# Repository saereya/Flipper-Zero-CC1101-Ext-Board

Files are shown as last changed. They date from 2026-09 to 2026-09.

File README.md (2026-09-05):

# Flipper Zero External CC1101 PCB

A PCB that plugs onto the Flipper Zero GPIO header and carries an external
CC1101 sub-GHz module, so you can use a better antenna than the built-in radio.
It also brings out the Flipper signals the radio does not use, and has a
prototyping area for further development.

## V2 — current design

**[CC1101ExtBoardV2/](CC1101ExtBoardV2/)** — KiCad 10, 61.34 × 32.84 mm, two
layers, hand-solderable. ERC and DRC clean, schematic and board in parity, with
gerbers, drill, BOM, position file and reports committed.

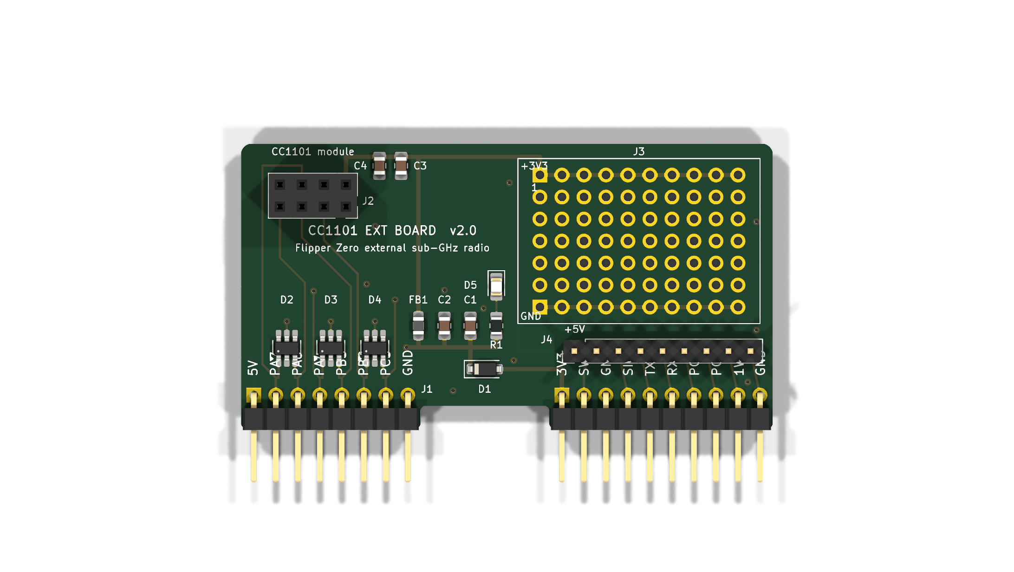
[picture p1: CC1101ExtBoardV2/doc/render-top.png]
V2 board


The radio now runs from Flipper pin 9 (+3V3) through a series Schottky and a
ferrite bead — no regulator and no zener. Every one of the eighteen connector
pads carries a real net, GDO2 is broken out to pin 7, ESD arrays sit at the
connector, ground is poured on both layers, and the prototyping grid is a true
2.54 mm array with rails on real nets.

See [CC1101ExtBoardV2/README.md](CC1101ExtBoardV2/README.md) for the pin map,
the bill of materials, the setup step you need on the Flipper, and a full
account of what changed and why.

One correction worth flagging: the V1 review claimed the connector could not
mate with a Flipper Zero because the GPIO header is "two rows of nine". It is
not. The Flipper Zero GPIO is a single row of 18 pins, split 8 + 10 with a
17.78 mm gap, 58.42 mm from pad 1 to pad 18 — exactly what V1 had. That
geometry was right and V2 keeps it. Everything else in the review was real and
is fixed.

## V1 — original design

**[CC1101ExtBoard/](CC1101ExtBoard/)** — kept for reference. Do not build it:
its 3.6 V zener is fitted backwards across the supply, its regulator has input
and output on the same net, and the radio is fed from the Flipper's +5V pin.

V1 protoboard design

V1 schematic

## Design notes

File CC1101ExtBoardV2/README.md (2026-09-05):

# CC1101 Ext Board V2

A Flipper Zero GPIO carrier for the common 8-pin CC1101 sub-GHz module, with a
prototyping area and a breakout for the Flipper signals the radio does not use.

61.34 × 32.84 mm, two layers, hand-solderable throughout (0805 passives, SOT-23-6,
SOD-123). ERC and DRC are clean; the only remaining DRC entries are silkscreen
overlap warnings where a connector's own pin labels sit close to its pads.

Top

## Wiring

The Flipper Zero GPIO is a **single row of 18 pins**, split into an 8-pin group
(pins 1–8) and a 10-pin group (pins 9–18) with a 17.78 mm gap, 58.42 mm from
pad 1 to pad 18. J1 is the full 18-pin right-angle male header, so its pins bend
down past the mating edge into the Flipper's female sockets and the board lies in
the plane of the GPIO field.

| Flipper pin | Signal | Net on this board | CC1101 module | Notes |
|---|---|---|---|---|
| 1 | +5V | `+5V` | — | Breakout J4 pin 1 only. Off by default; enable it in the GPIO menu. |
| 2 | PA7 | `/MOSI` | MOSI (6) | Clamped by D2 |
| 3 | PA6 | `/MISO` | MISO (7) | Clamped by D2 |
| 4 | PA4 | `/CSN` | CSN (4) | Clamped by D3 |
| 5 | PB3 | `/SCK` | SCK (5) | Clamped by D3 |
| 6 | PB2 | `/GDO0` | GDO0 (3) | Clamped by D4 |
| 7 | PC3 | `/GDO2` | GDO2 (8) | Clamped by D4. V1 left this pin unused. |
| 8 | GND | `GND` | GND (1) | |
| 9 | +3V3 | `+3V3` | — | The only supply the radio uses. 1.2 A available. |
| 10 | SWC | `/SWC` | — | Breakout J4 pin 2 |
| 11 | GND | `GND` | — | |
| 12 | SIO | `/SIO` | — | Breakout J4 pin 3 |
| 13 | TX | `/TX` | — | Breakout J4 pin 4 |
| 14 | RX | `/RX` | — | Breakout J4 pin 5 |
| 15 | PC1 | `/PC1` | — | Breakout J4 pin 6 |
| 16 | PC0 | `/PC0` | — | Breakout J4 pin 7 |
| 17 | 1W | `/1W` | — | Breakout J4 pin 8 |
| 18 | GND | `GND` | — | Breakout J4 pin 9 |

All eighteen pads carry a net. No power pin is silenced with a no-connect flag.

## Power tree

```
J1.9 (+3V3, from the Flipper)
  └─ D1  PMEG2010EH        series Schottky, reverse and back-feed protection
      └─ +3V3_SYS          C1 10 µF, C2 100 nF, R1+D5 indicator, ESD array rails
          └─ FB1 600 R @ 100 MHz
              └─ +3V3_RF   C3 10 µF, C4 100 nF, J2 pin 2 (module VCC),
                           and the proto-area +3V3 rail
```

There is no regulator and no zener. The CC1101 operates from 1.8 V to 3.6 V with
an absolute maximum of 3.9 V, so the Flipper's own 3.3 V rail is the correct
supply; output power is set by PATABLE, not by supply voltage. Budget about
0.25 V of drop across D1 at the module's ~35 mA transmit current, leaving roughly
3.05 V at the socket.

## Using it

1. Plug the CC1101 module into J2. Pin 1 (GND) is the square pad, marked on the
   silkscreen; the module hangs over the board, clear of the 0805 passives.
2. Fit the board onto the Flipper's GPIO sockets. The 8 + 10 split is
   self-keying — it will not mate rotated.
3. On the Flipper: **Sub-GHz → Radio Settings → Module: External**.
4. D5 lights when the board has power. Nothing needs the +5V pin.

## Bill of materials

| Ref | Value | Package | Purpose |
|---|---|---|---|
| J1 | Flipper Zero GPIO | 1×08 + 1×10 right-angle **male pin header**, 2.54 mm | Plugs into the Flipper's female GPIO sockets |
| J2 | CC1101 module | 2×04 socket, 2.54 mm | Radio module |
| J3 | 50 pads, 2.54 mm | THT grid | Prototyping area, +3V3 and GND rails |
| J4 | Spare pins | 1×09 header, 2.54 mm | Breakout: +5V, SWC, SIO, TX, RX, PC1, PC0, 1W, GND |
| D1 | PMEG2010EH | SOD-123 | Series Schottky |
| D2–D4 | SRV05-4 | SOT-23-6 | ESD rail-clamp arrays, ~3 pF per line |
| D5 | LED (red) | 0805 | Power indicator |
| FB1 | 600 R @ 100 MHz | 0805 | Radio supply filter |
| C1, C3 | 10 µF | 0805 | Bulk, each side of FB1 |
| C2, C4 | 100 nF | 0805 | HF decoupling, each side of FB1 |
| R1 | 1 kΩ | 0805 | LED series resistor (~1.5 mA) |

`doc/bom.csv` is the generated version. J1 is **male** right-angle headers —
the Flipper Zero's GPIO is female. J2 is a female socket, because the CC1101
module has male pins.

## What changed from V1

Driven by the V1 design review. Every fix and the one finding that turned out to
be wrong:

| Errata item | V2 |
|---|---|
| PWR·1 reversed 3.6 V zener | Deleted. The Flipper regulates this rail. |
| PWR·2 regulator input and output on one net | LF33 deleted; the radio runs from Flipper pin 9. |
| PWR·3 radio fed from +5V | Supply is now pin 9 (+3V3) through D1 and FB1. |
| PWR·4 10 Ω LED resistor | R1 = 1 kΩ, about 1.5 mA. |
| **CONN·1 "connector cannot mate"** | **Wrong finding.** The Flipper GPIO really is one row of 18 split 8 + 10 over 58.42 mm, exactly as V1 had it. There is no 2×09 header. V1's connector geometry was correct and V2 keeps it. |
| SYNC·1 headers unannotated and unlinked | One annotated `J1` from the schematic, with a `path` back to its symbol. Schematic-parity check passes. |
| SYNC·2 no supply or ground return in the schematic | J1's supply pins are typed `power_out`; a PWR_FLAG marks the ground return. No no-connects on power pins. |
| SYNC·3 netless tracks and vias | Every track and via carries a net. Both prototyping rails are real nets that DRC checks. |
| MECH·1 prototyping grid off 0.1 inch | One footprint, true 2.54 mm in both axes, 10 × 5 pads plus two 10-pad rails. |
| FAB·1 objects outside the outline | Nothing outside the outline; copper-to-edge is an error at 0.3 mm. |
| FAB·2 zeroed design rules | Real rules: 0.15 mm clearance and track, 0.3 mm hole and edge, 0.05 mm mask expansion, 0.25 mm mask sliver. |
| BOM·1 LF33 symbol/value/footprint disagree | Regulator gone. Every remaining part's symbol, value and footprint agree. |
| GND·1 one ground pin, half a pour | All three Flipper grounds connected, GND poured on both layers with 10 stitching vias. |
| FUNC·1 GDO2 unused | GDO2 → Flipper pin 7 (PC3). |
| DOC·1 README overstates protection | This file: real wiring table, real protection, and the *Module: External* step. |
| REPO·1 generated files committed | `.gitignore` added at the repo root. Fab and documentation outputs are committed under `fab/` and `doc/`. |
| Rework step 3, ESD | Three SRV05-4 arrays, two channels each, so every clamp sits within about 2 mm of its connector pin. Six spare channels. |
| Rework step 7, current KiCad | KiCad 10 project throughout. |

## Layout notes and liberties taken

- **Mechanical reference.** J1's footprint is `FLIPPER-GPIO-18-RA` from
  [kbembedded/flipper-gpio-eda](https://github.com/kbembedded/flipper-gpio-eda)
  (BSD-2-Clause, see `library/LICENSE.flipper-gpio-eda`), which carries Flipper's
  own recommended board-edge profile on `User.Drawings`. The board outline traces
  it: the mating edge sits 3.84 mm below the pin row under each connector group
  and steps back to 1.24 mm across the gap, with 0.5 mm corner rounds.
  **Dry-fit before ordering** — the profile is from Flipper's published
  blueprint, not from a measured device.
- **3D models on J1.** Two edits to the upstream footprint, so the 3D preview is
  usable as a mechanical check. Upstream references a single eight-way model,
  unrotated, which lies *across* the pad row and covers only pads 1 and 9;
  replaced with both `PinHeader_1x08` and `PinHeader_1x10_P2.54mm_Horizontal` on
  the KiCad 10 model path, each rotated +90° about Z and offset by its own
  pin-field length. The rotation is needed because KiCad's standard 1×NN
  footprints run their pads along Y with the body on +X, while this footprint
  runs its pads along X with the body toward the mating edge; the offset slides
  each bar back over its own pads, since +90° also maps the pad axis onto −X.
  The only residual is that the pin-1 chamfer lands at the far end of each bar,
  which the square pad and silkscreen already mark correctly. The pads
  themselves were always a single row — this was a preview-only defect.
- **ESD split three ways.** A single SRV05-4 has its four I/O pads on only two
  x positions, which forces the SPI traces to cross to reach it. Three arrays let
  every tap be a straight stub off the connector pin, which is also what the
  part's own placement guidance asks for. The cost is six unused channels.
- **Series Schottky.** The errata asks for one. It is worth noting that the
  8 + 10 split makes a rotated mis-plug physically impossible, so D1's real value
  is blocking the board's 20 µF of bulk from back-feeding the Flipper's rail and
  surviving a partial insertion. If the 0.25 V drop matters more than that,
  fit a 0 Ω link in its place.
- **Module orientation.** J2 is placed so the module can overhang the top edge or
  lie over the board; nothing on the board is taller than 0.7 mm, and the socket
  raises the module about 8.5 mm. Which way the module body points depends on the
  module, so this has not been verified against a physical part.
- **Ground pour on both layers.** Signals are on F.Cu; +5V, and the three nets
  whose routing order does not match the module's pinout (`/CSN`, `/GDO2`, and the
  ESD rail feed), use short B.Cu runs.

## Files

```
CC1101ExtBoardV2.kicad_pro/_sch/_pcb   the design
library/CC1101ExtBoardV2.kicad_sym     project symbols
library/CC1101ExtBoardV2.pretty        project footprints
doc/                                   ERC, DRC, schematic PDF, renders, BOM, netlist
fab/                                   gerbers + drill (zipped), positions, STEP
build-outputs.sh                       regenerates everything in doc/ and fab/
```

`./build-outputs.sh` needs `kicad-cli` 10.x; it falls back to a
`~/.local/bin/kicad-*.AppImage` if `kicad-cli` is not on `PATH`, or set
`KICAD_CLI` yourself.

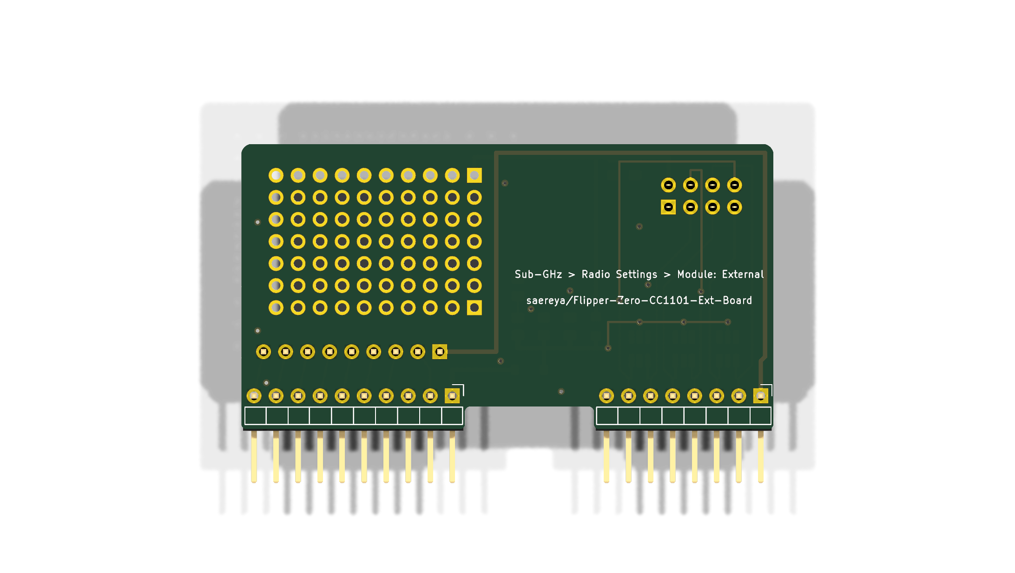
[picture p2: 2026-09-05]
CC1101ExtBoardV2/doc/render-bottom.png

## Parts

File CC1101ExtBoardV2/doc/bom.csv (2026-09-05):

Refs | Value | Footprint | Qty | Datasheet
C1,C3 | 10uF | Capacitor_SMD:C_0805_2012Metric_Pad1.18x1.45mm_HandSolder | 2
C2,C4 | 100nF | Capacitor_SMD:C_0805_2012Metric_Pad1.18x1.45mm_HandSolder | 2
D1 | PMEG2010EH | Diode_SMD:D_SOD-123 | 1
D2-D4 | SRV05-4 | Package_TO_SOT_SMD:SOT-23-6_Handsoldering | 3
D5 | LED | LED_SMD:LED_0805_2012Metric_Pad1.15x1.40mm_HandSolder | 1
FB1 | 600R@100MHz | Inductor_SMD:L_0805_2012Metric_Pad1.05x1.20mm_HandSolder | 1
J1 | Flipper Zero GPIO | CC1101ExtBoardV2:FLIPPER-GPIO-18-RA | 1 | https://docs.flipper.net/zero/gpio-and-modules
J2 | CC1101 Module | Connector_PinSocket_2.54mm:PinSocket_2x04_P2.54mm_Vertical | 1
J3 | 50 pads, 2.54 mm | CC1101ExtBoardV2:ProtoGrid_10x5_P2.54mm | 1
J4 | Spare pins | Connector_PinHeader_2.54mm:PinHeader_1x09_P2.54mm_Vertical | 1
R1 | 1kR | Resistor_SMD:R_0805_2012Metric_Pad1.20x1.40mm_HandSolder | 1

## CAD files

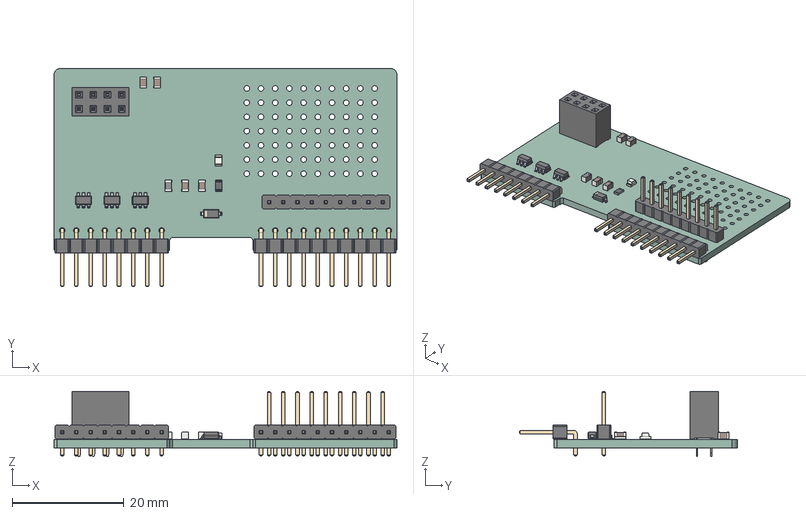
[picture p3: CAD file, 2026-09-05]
CC1101ExtBoardV2/fab/CC1101ExtBoardV2.step
61.3 x 39.0 x 11.6 mm
PinHeader_1x08_P254mm_Horizontal
PinHeader_1x10_P254mm_Horizontal
C_0805_2012Metric x 4
R_0805_2012Metric
PinSocket_2x04_P2.54mm_Vertical
SOT-23-6 x 3
LED_0805_2012Metric
L_0805_2012Metric
D_SOD-123
PinHeader_1x09_P254mm_Vertical
CC1101ExtBoardV2_PCB

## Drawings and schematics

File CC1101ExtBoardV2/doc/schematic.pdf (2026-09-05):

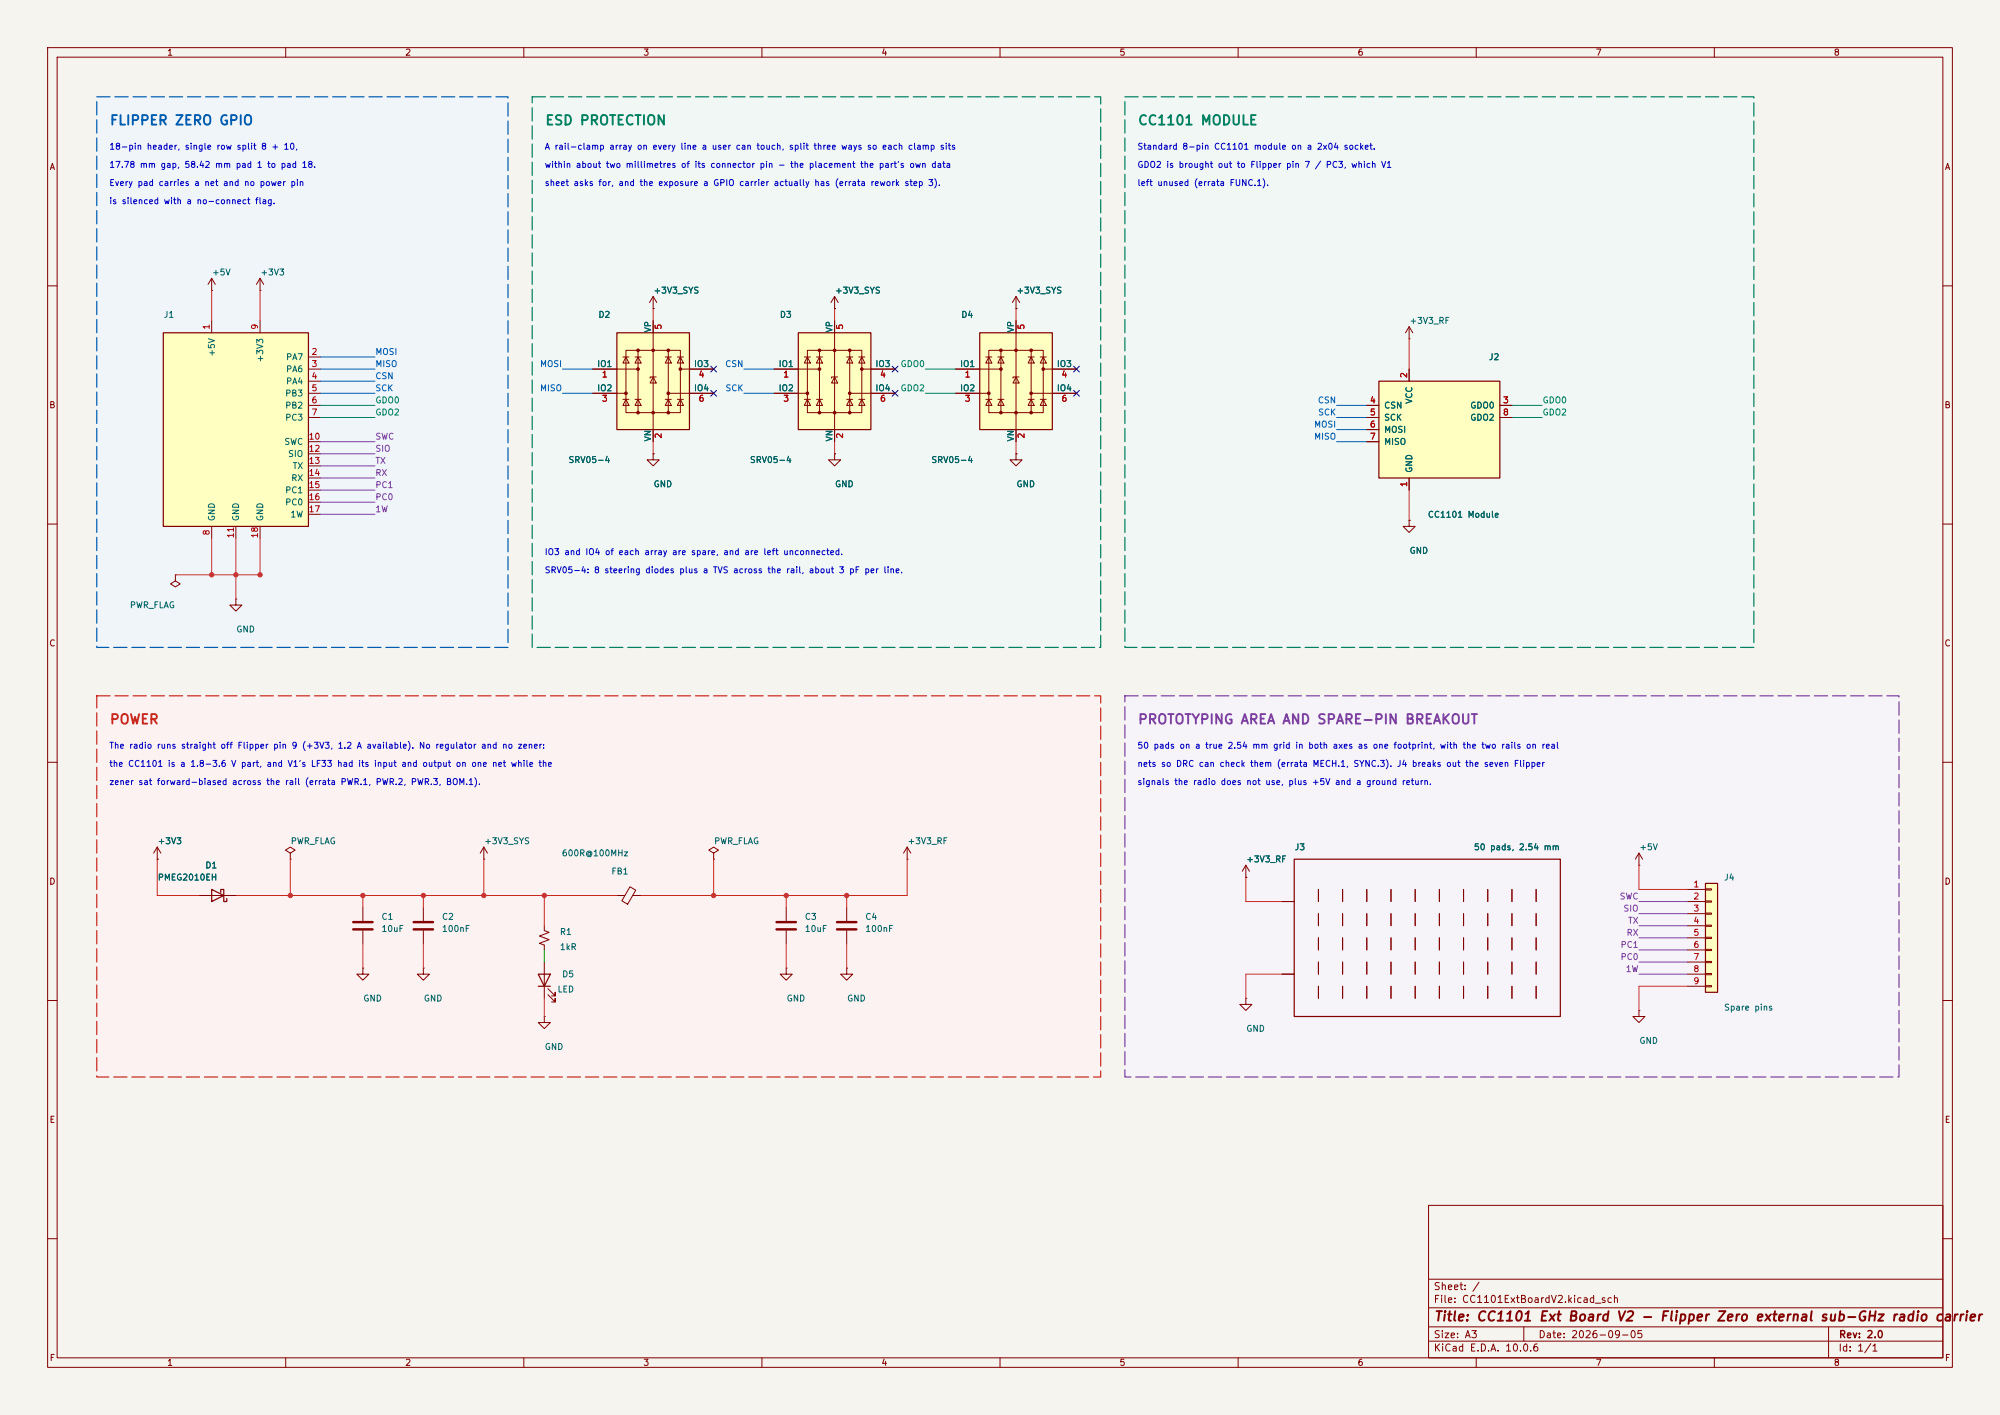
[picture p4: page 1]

IO3 and IO4 of each array are spare, and are left unconnected. SRV05-4: 8 steering diodes plus a TVS across the rail, about 3 pF per line. ESD PROTECTION

18-pin header, single row split 8 + 10,

Standard 8-pin CC1101 module on a 2x04 socket. GDO2 is brought out to Flipper pin 7 / PC3, which V1

is silenced with a no-connect flag. 17.78 mm gap, 58.42 mm pad 1 to pad 18. Every pad carries a net and no power pin

within about two millimetres of its connector pin - the placement the part's own data

left unused (errata FUNC.1).

the CC1101 is a 1.8-3.6 V part, and V1's LF33 had its input and output on one net while the POWER

zener sat forward-biased across the rail (errata PWR.1, PWR.2, PWR.3, BOM.1). The radio runs straight off Flipper pin 9 (+3V3, 1.2 A available). No regulator and no zener:

50 pads on a true 2.54 mm grid in both axes as one footprint, with the two rails on real

nets so DRC can check them (errata MECH.1, SYNC.3). J4 breaks out the seven Flipper

signals the radio does not use, plus +5V and a ground return.

File: CC1101ExtBoardV2.kicad_sch
Title: CC1101 Ext Board V2 - Flipper Zero external sub-GHz radio carrier

Size: A3 | Rev: 2.0 | F Date: 2026-09-05
KiCad E.D.A. 10.0.6 | Id: 1/1

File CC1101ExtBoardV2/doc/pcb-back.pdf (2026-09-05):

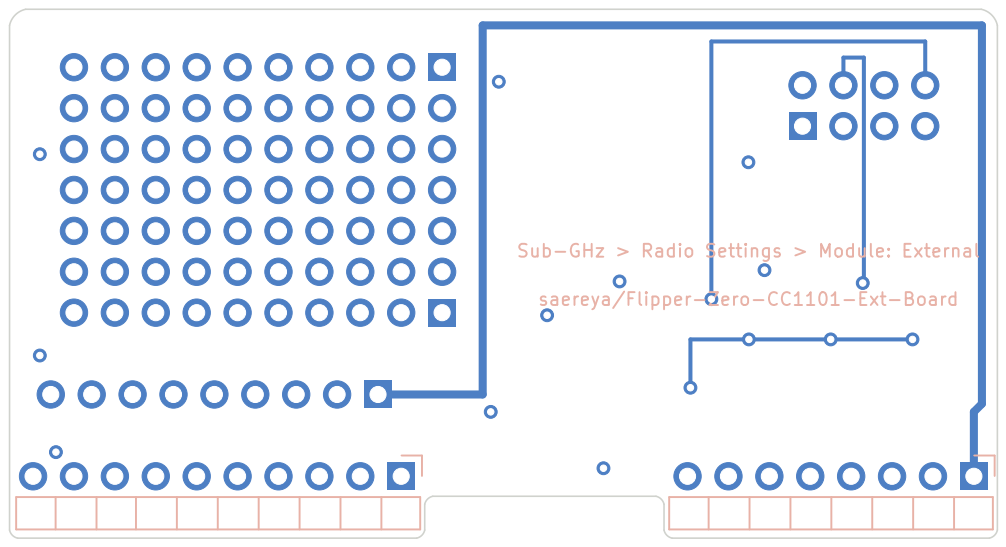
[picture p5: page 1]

Sub-GHz > Radio Settings > Module: External saereya/Flipper-Zero-CC1101-Ext-Board

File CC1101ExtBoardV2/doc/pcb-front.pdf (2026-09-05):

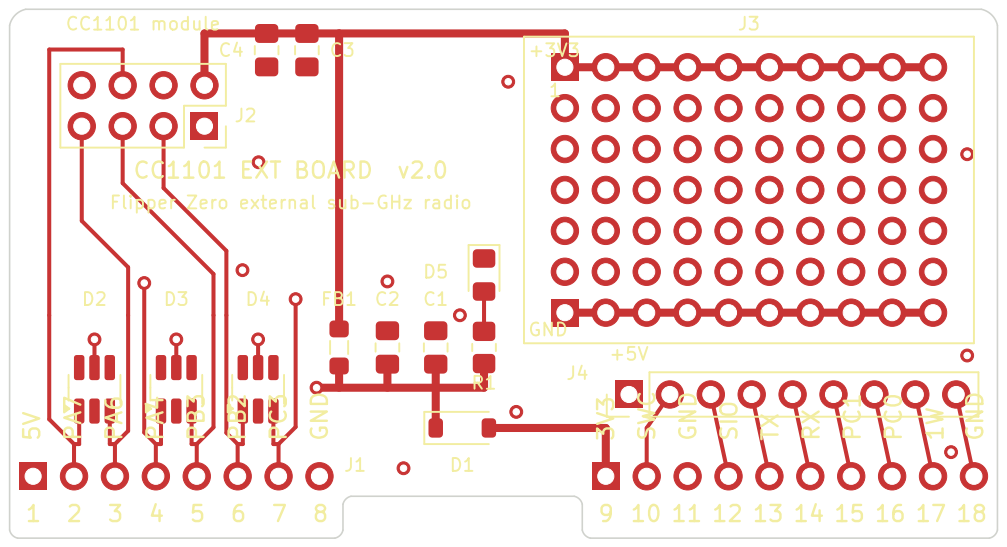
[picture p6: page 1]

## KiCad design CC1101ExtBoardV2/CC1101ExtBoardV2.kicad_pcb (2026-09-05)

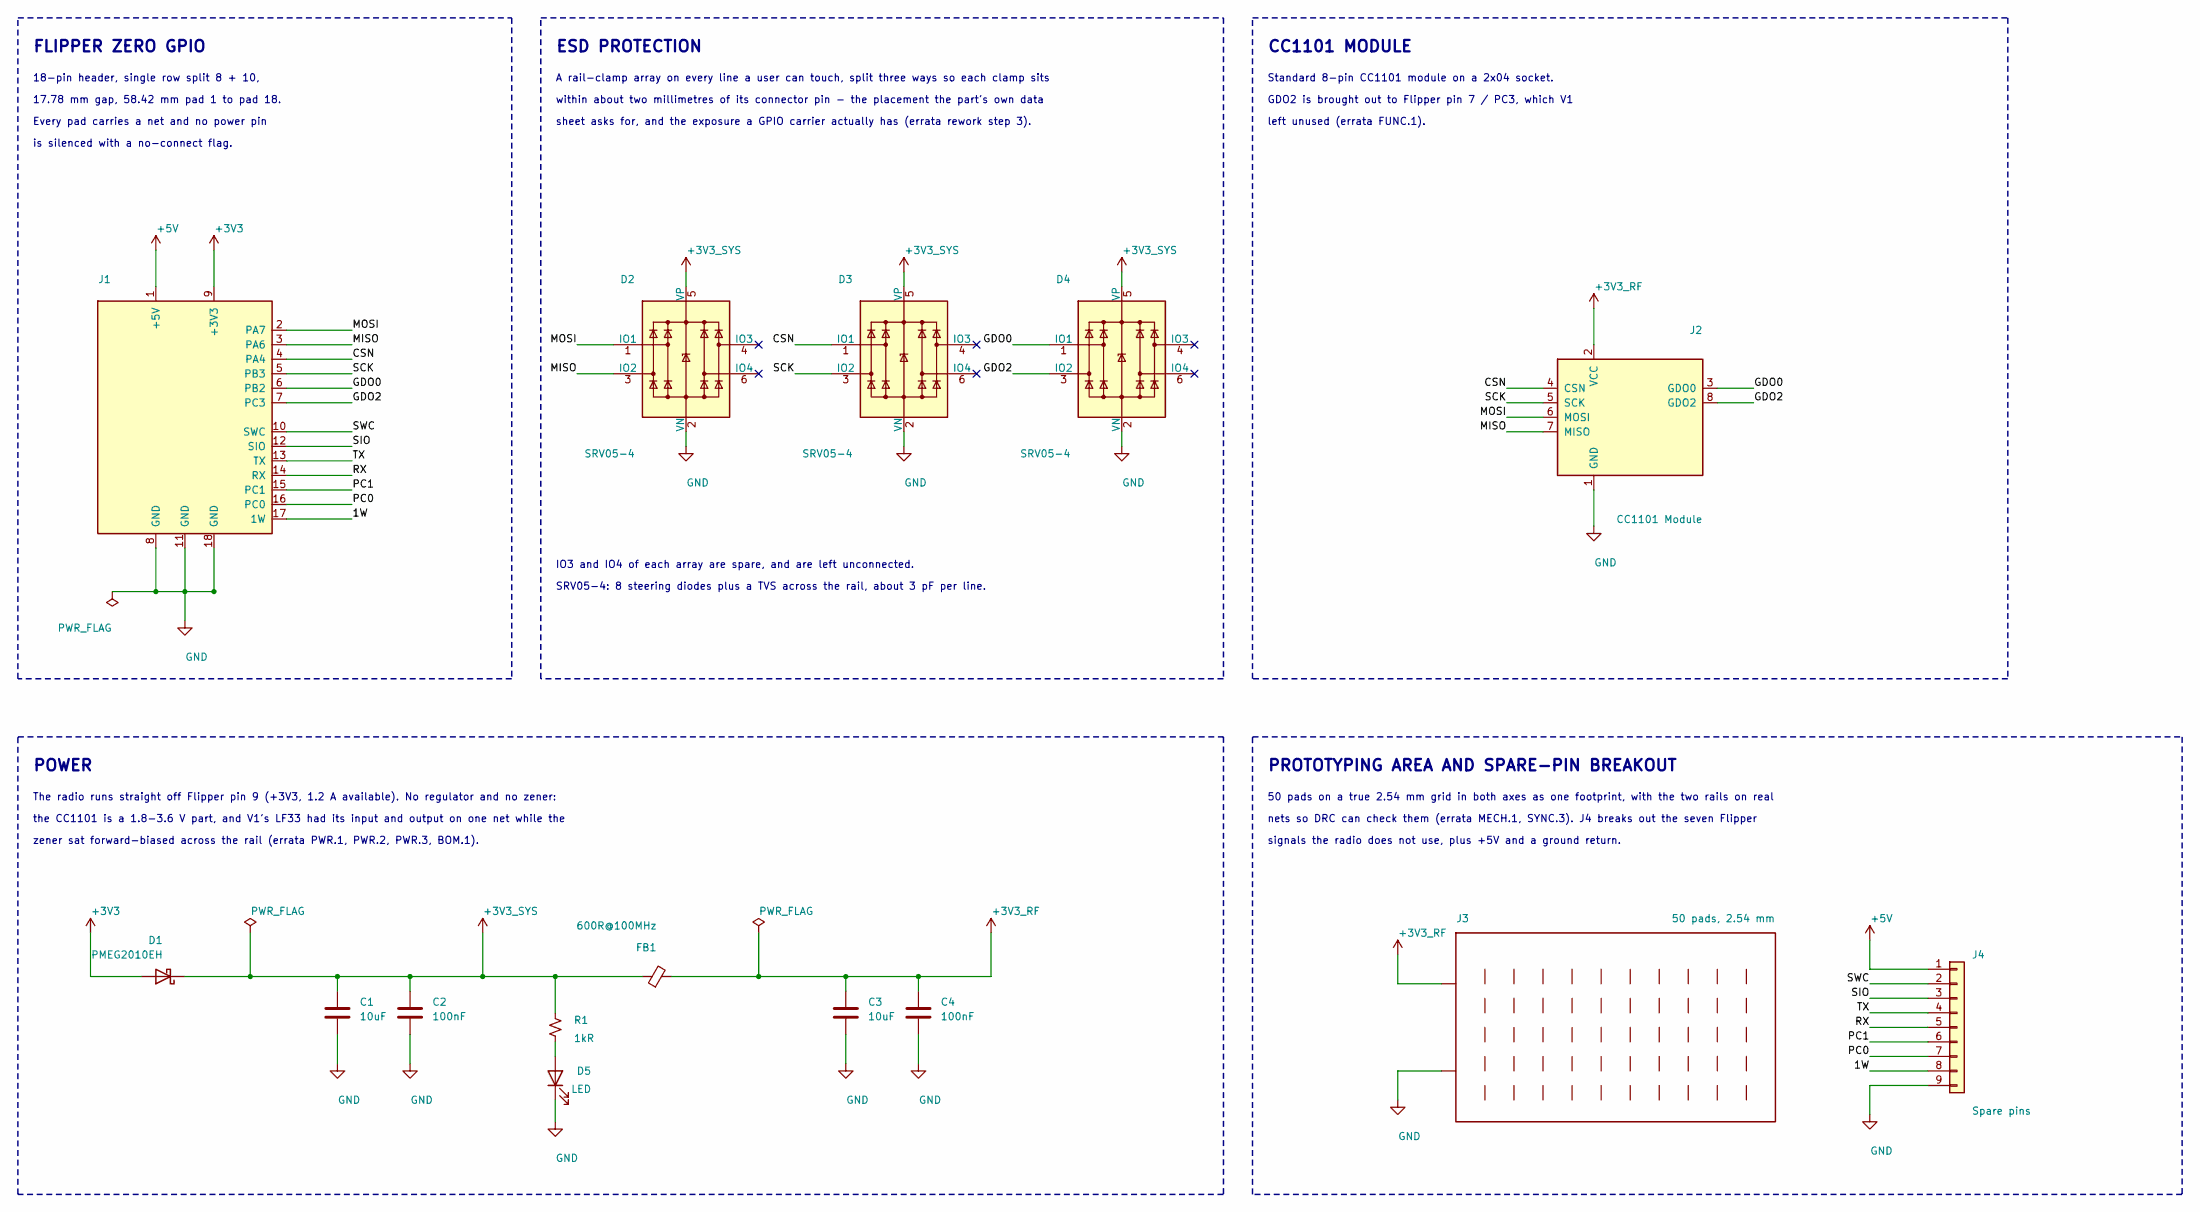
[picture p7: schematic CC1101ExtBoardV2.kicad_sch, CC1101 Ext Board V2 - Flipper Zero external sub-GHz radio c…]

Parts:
C1, C3: 10uF; C_0805_2012Metric_Pad1.18x1.45mm_HandSolder
C2, C4: 100nF; C_0805_2012Metric_Pad1.18x1.45mm_HandSolder
D1: PMEG2010EH; D_SOD-123
D2, D3, D4: SRV05-4; SOT-23-6_Handsoldering
D5: LED; LED_0805_2012Metric_Pad1.15x1.40mm_HandSolder
FB1: 600R@100MHz; L_0805_2012Metric_Pad1.05x1.20mm_HandSolder
J1: Flipper Zero GPIO; FLIPPER-GPIO-18-RA
J2: CC1101 Module; PinSocket_2x04_P2.54mm_Vertical
J3: 50 pads, 2.54 mm; ProtoGrid_10x5_P2.54mm
J4: Spare pins; PinHeader_1x09_P2.54mm_Vertical
R1: 1kR; R_0805_2012Metric_Pad1.20x1.40mm_HandSolder

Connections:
+3V3: D1.2 (A), J1.9 (+3V3)
+3V3_RF: C3.1, C4.1, FB1.2, J2.2 (VCC), J3.51 (+3V3_RF)
+3V3_SYS: C1.1, C2.1, D1.1 (K), D2.5 (VP), D3.5 (VP), D4.5 (VP), FB1.1, R1.1
+5V: J1.1 (+5V), J4.1
/1W: J1.17 (1W), J4.8
/CSN: D3.1 (IO1), J1.4 (PA4), J2.4 (CSN)
/GDO0: D4.1 (IO1), J1.6 (PB2), J2.3 (GDO0)
/GDO2: D4.3 (IO2), J1.7 (PC3), J2.8 (GDO2)
/MISO: D2.3 (IO2), J1.3 (PA6), J2.7 (MISO)
/MOSI: D2.1 (IO1), J1.2 (PA7), J2.6 (MOSI)
/PC0: J1.16 (PC0), J4.7
/PC1: J1.15 (PC1), J4.6
/RX: J1.14 (RX), J4.5
/SCK: D3.3 (IO2), J1.5 (PB3), J2.5 (SCK)
/SIO: J1.12 (SIO), J4.3
/SWC: J1.10 (SWC), J4.2
/TX: J1.13 (TX), J4.4
GND: C1.2, C2.2, C3.2, C4.2, D2.2 (VN), D3.2 (VN), D4.2 (VN), D5.1 (K), J1.8 (GND), J1.11 (GND), J1.18 (GND), J2.1 (GND), J3.52 (GND), J4.9
unnamed: D5.2 (A), R1.2

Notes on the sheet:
IO3 and IO4 of each array are spare, and are left unconnected.
A rail-clamp array on every line a user can touch, split three ways so each clamp sits
nets so DRC can check them (errata MECH.1, SYNC.3). J4 breaks out the seven Flipper
FLIPPER ZERO GPIO
the CC1101 is a 1.8-3.6 V part, and V1's LF33 had its input and output on one net while the
18-pin header, single row split 8 + 10,
POWER
is silenced with a no-connect flag.
within about two millimetres of its connector pin - the placement the part's own data
CC1101 MODULE
Standard 8-pin CC1101 module on a 2x04 socket.
sheet asks for, and the exposure a GPIO carrier actually has (errata rework step 3).
GDO2 is brought out to Flipper pin 7 / PC3, which V1
zener sat forward-biased across the rail (errata PWR.1, PWR.2, PWR.3, BOM.1).
50 pads on a true 2.54 mm grid in both axes as one footprint, with the two rails on real
SRV05-4: 8 steering diodes plus a TVS across the rail, about 3 pF per line.
PROTOTYPING AREA AND SPARE-PIN BREAKOUT
signals the radio does not use, plus +5V and a ground return.
The radio runs straight off Flipper pin 9 (+3V3, 1.2 A available). No regulator and no zener:
17.78 mm gap, 58.42 mm pad 1 to pad 18.
left unused (errata FUNC.1).
ESD PROTECTION
Every pad carries a net and no power pin

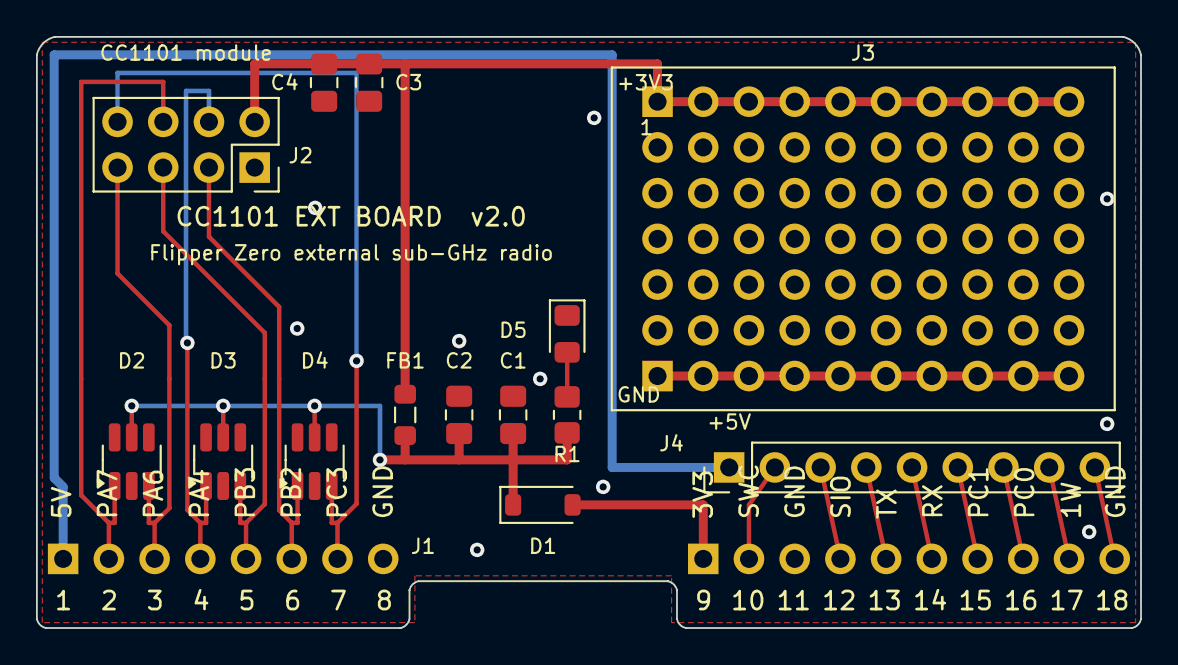
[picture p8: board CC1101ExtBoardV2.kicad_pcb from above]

Board: 2 copper layers, 61.3 x 32.8 mm, 15 parts (0 on the bottom side), 19 nets.
